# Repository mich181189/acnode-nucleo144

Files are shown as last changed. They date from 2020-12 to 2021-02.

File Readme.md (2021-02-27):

ACNode Nucleo-144 Overlay
=========

# What Is This?
This is an **unfinished** design for an addon board to fit a Nucleo-144, turning it into an ACNode.

# Why?
The current ACNode hardware and software (https://github.com/londonhackspace/acnode-cl) is based around a TI Connected Launchpad. These no doubt looked cool when they were new, but there haven't been any new revisions for some time. On top of this, the current code is based around Energia, an Arduino port for TI Connected Launchpads.

Nowadays, there are other inexpensive development boards available with Ethernet. ST make a large range of Nucleo-144 boards for various microcontrollers. They're more capable, and seem to have better software support.

The software could really do with a rewrite anyway, so there isn't much lost there. It should be possible to make software that builds for both TI Connected Launchpads and ST Nucleo boards (Early-ish work based on FreeRTOS here: https://github.com/mich181189/acnode-cl)

# Features
* Connects to a Nucleo-144 board
* Provides connections to both existing 8P8C readers and the new (still in development, though coming along nicely) RS-422 connected serial readers
* 7-12V input with reverse polarity protection
* SPI Flash for configuration and card caching
* On-board LED mirroring reader LED
* Isolated Tool On input (should accept 3.3-12V)
* Relay for turning on tools, opening doors e.t.c

# Changes from Existing ACNode Boards

* SPI Flash instead of SDCard
I don't think we've ever actually fitted the SD Card. The STM32 MCUs don't have built-in EEPROMs, and we need somewhere to store configuration. Putting these two observations together, it makes sense to fit some SPI storage (EEPROM or Flash) for storage. EEPROMs are easier to write small amounts to, but are smaller. Flash has a lower write cycle count, however tend to be larger, and with a wear levelling filesystem, should be fine.

* On-board LED
When an ACNode is mounted to the other side of a door to its reader, it can be difficult to see the state of the reader since the LED is on the other side of a door. The obvious solution to this is to also put an LED on the ACNode.

* On-board Button
Similar to the on-board LED, this mirrors the functionality of the button on the reader, for easier maintainence

* Isolated tool on pin
Tools can be noisy. By isolating the tool on signal using an optoisolator, we can reduce coupling between the tool and the ACNode.

* Provides RS-422 reader connection
Since we want to be able to use the new reader boards, we need a way to conect them.

* 7-12V input with reverse polarity protection
Not exactly a new requirement, but the Nucleo-144 boards have regulators built in with 7-12V input range, so we may as well add this as an option. Reverse polarity protection because it makes sense to have! A previous board does have a reverse-biased diode for polarity "protection" but it's probably more of a smoke signal.

# Nucleo-144 Boards
Nucleo-144 boards do vary a bit. This board is intended to work with the following boards (which have basically the same pin usage), however will probably work with many other Nucleo-144 boards:

| Board | Features | Example Price | Example Source |
| ----- | --- | --- | --- |
| NUCLEO-H743ZI2 | Arm Cortex M7 with 2MB Flash, 1MB RAM, L1 Cache, running at up to 480MHz | £26.21 | [https://uk.rs-online.com/web/p/microcontroller-development-tools/1939787/](RS 193-9787) |
| NUCLEO-F767ZI | Arm Cortex M7 with 2MB Flash, 512KB RAM, L1 Cache, running at up to 216MHz | £22.38 | [https://uk.rs-online.com/web/p/microcontroller-development-tools/1231052/](RS 123-1052) |
| NUCLEO-F756ZG | Arm Cortex M7 with 1MB Flash, 320KB RAM, L1 Cache, HW Crypto, running at up to 216MHz | £22.31 | [https://uk.rs-online.com/web/p/microcontroller-development-tools/1750680/](RS 175-0680) |

# TODO
* Exit Button Support
* A jumper on the ISL3176 ~RE line would allow a single	board to support 5V and 12V readers
* Footprints for 3.81mm	connectors are too tight - holes too small

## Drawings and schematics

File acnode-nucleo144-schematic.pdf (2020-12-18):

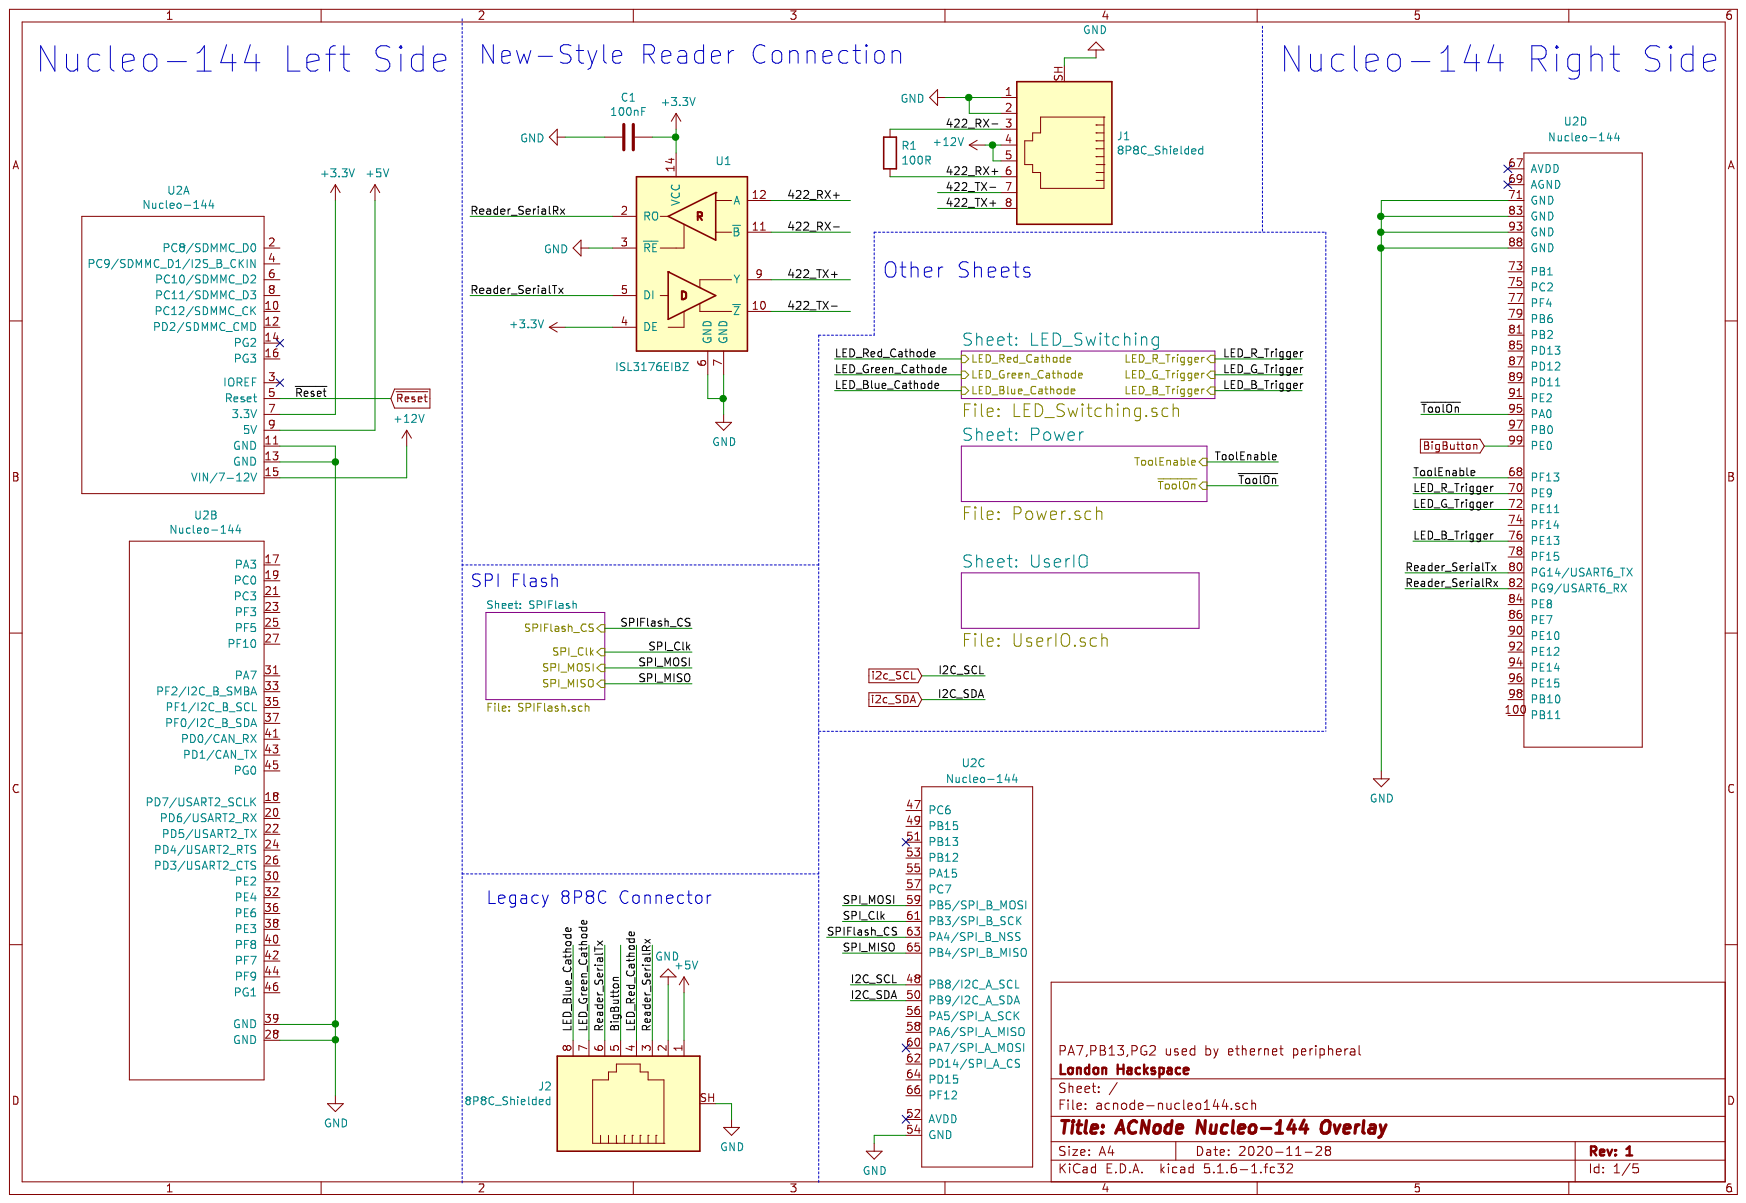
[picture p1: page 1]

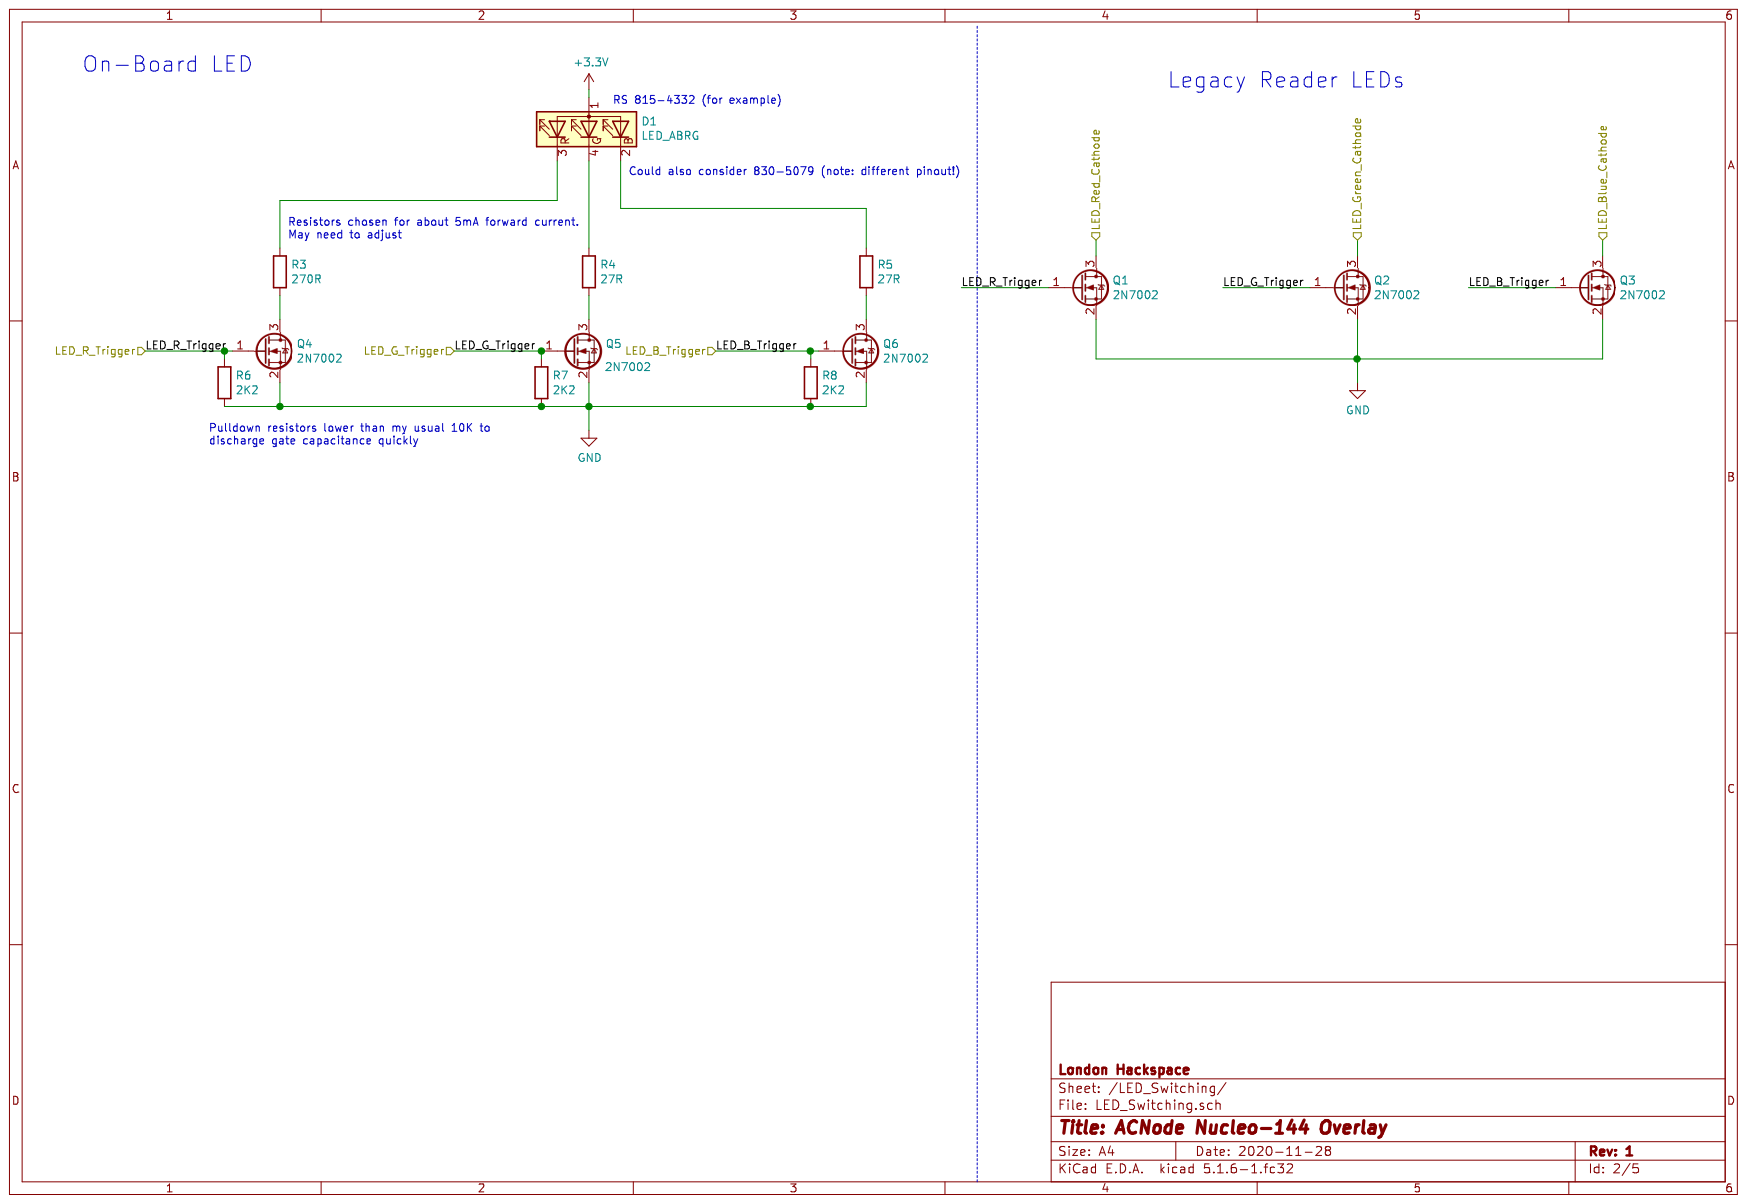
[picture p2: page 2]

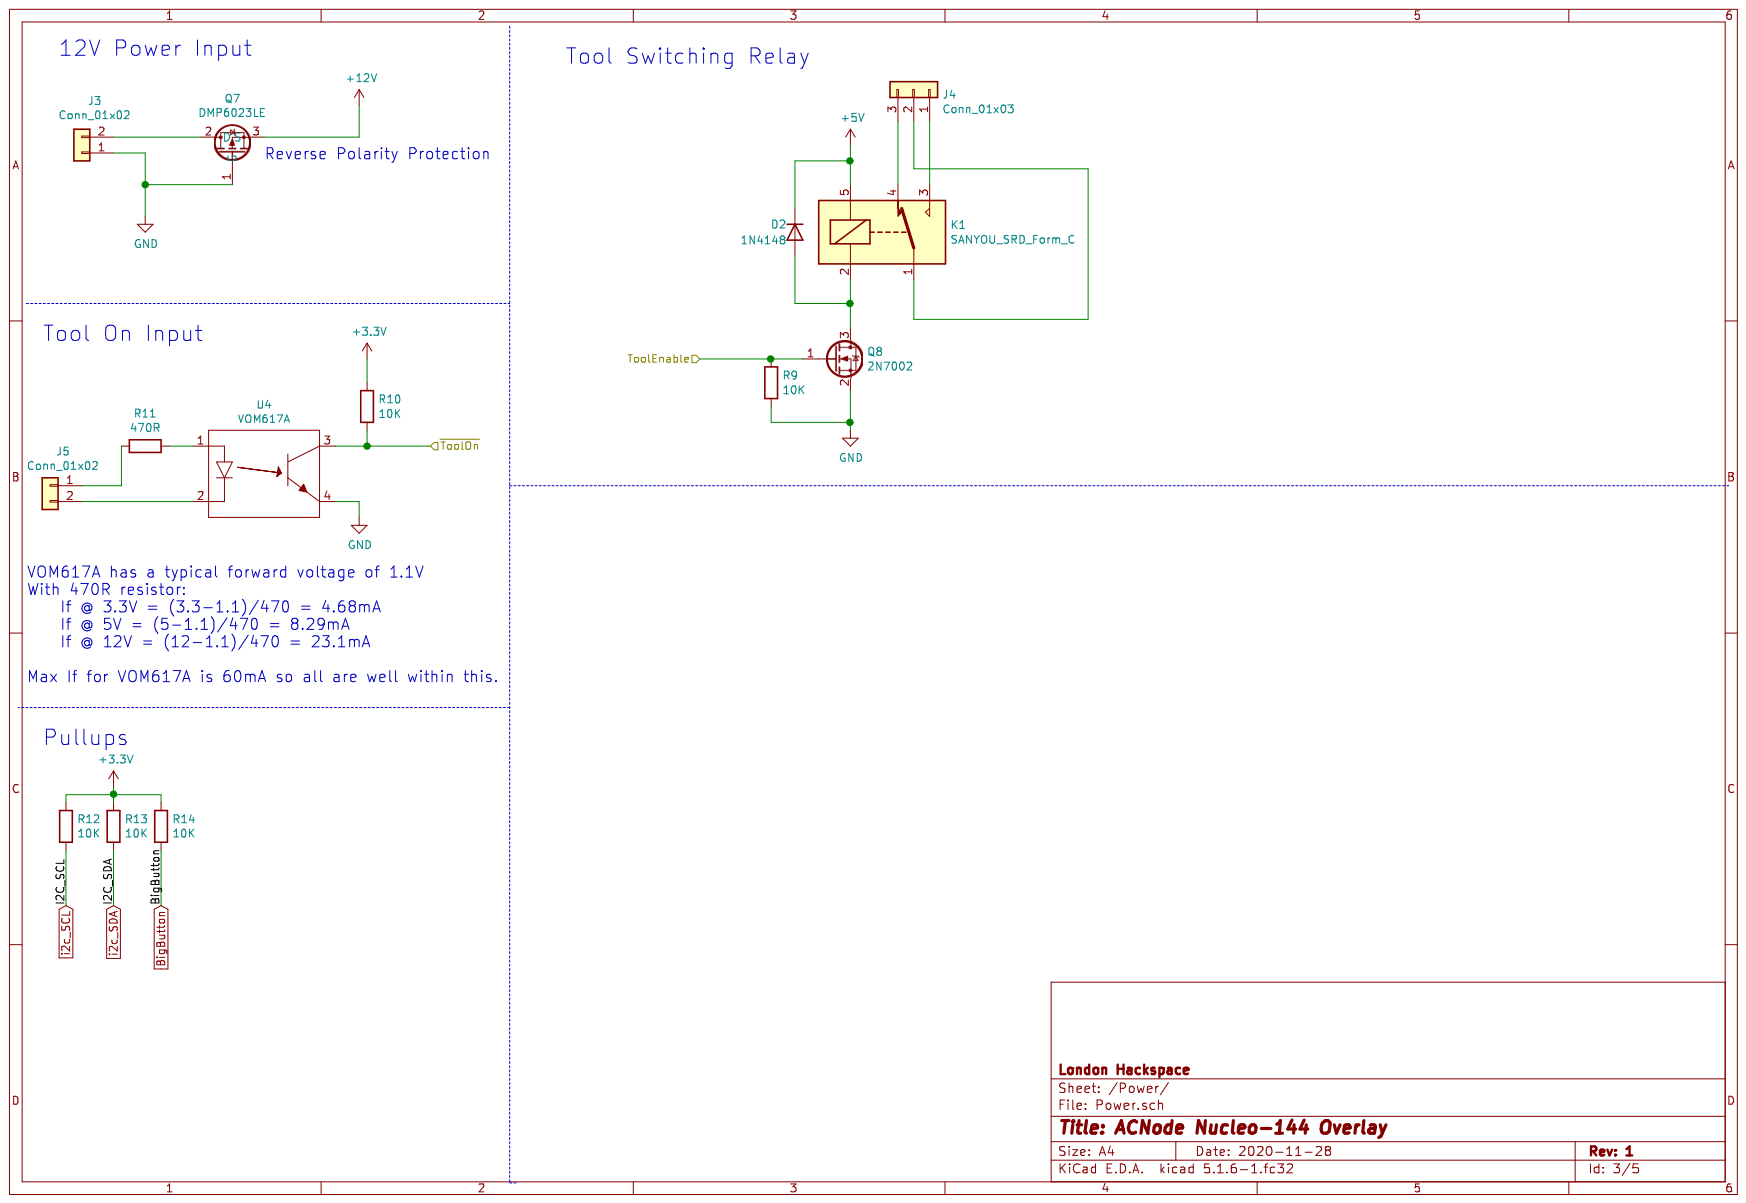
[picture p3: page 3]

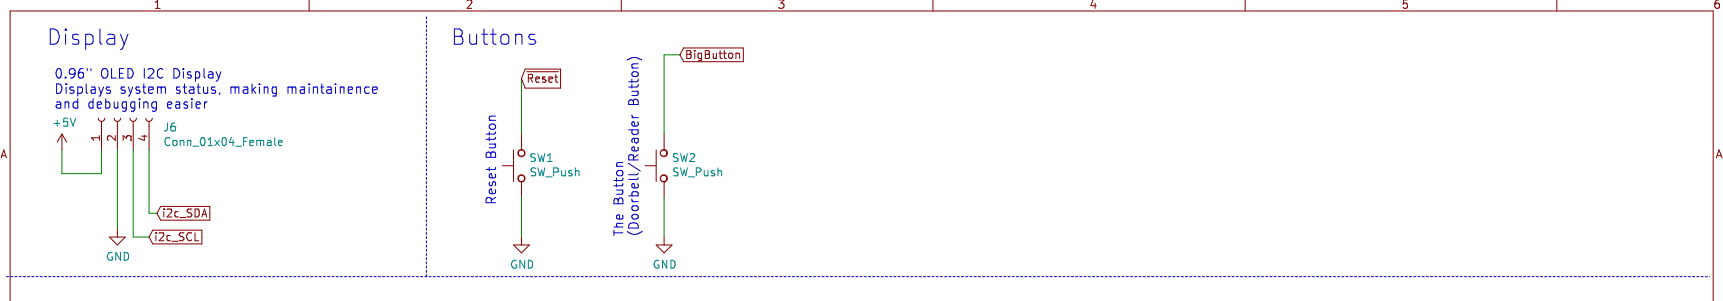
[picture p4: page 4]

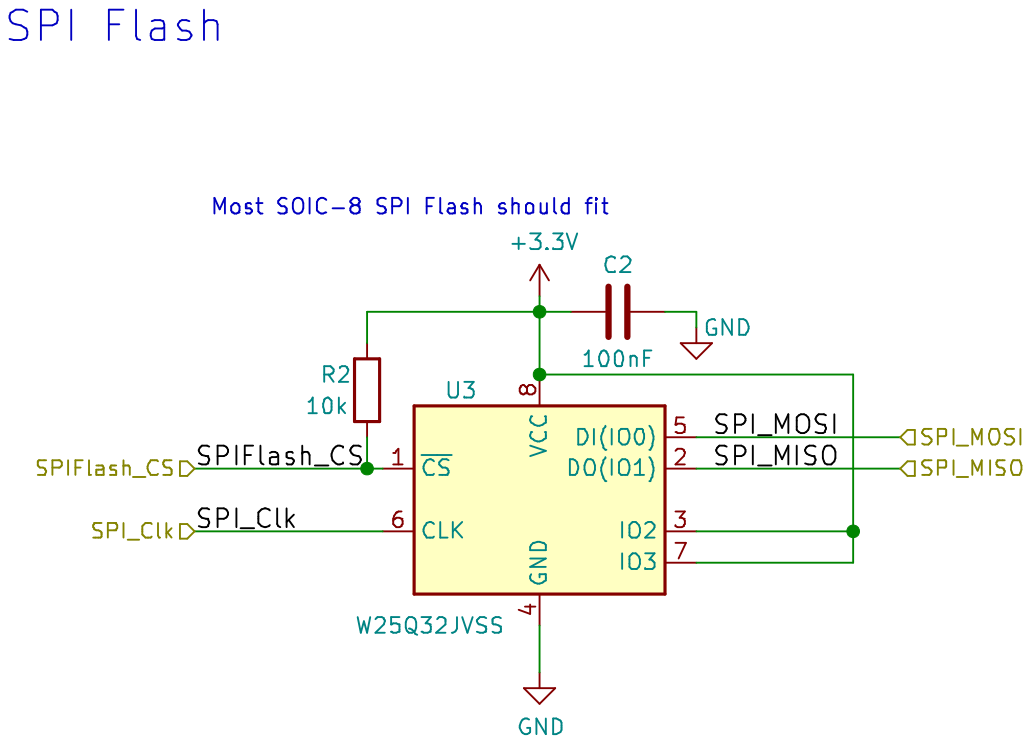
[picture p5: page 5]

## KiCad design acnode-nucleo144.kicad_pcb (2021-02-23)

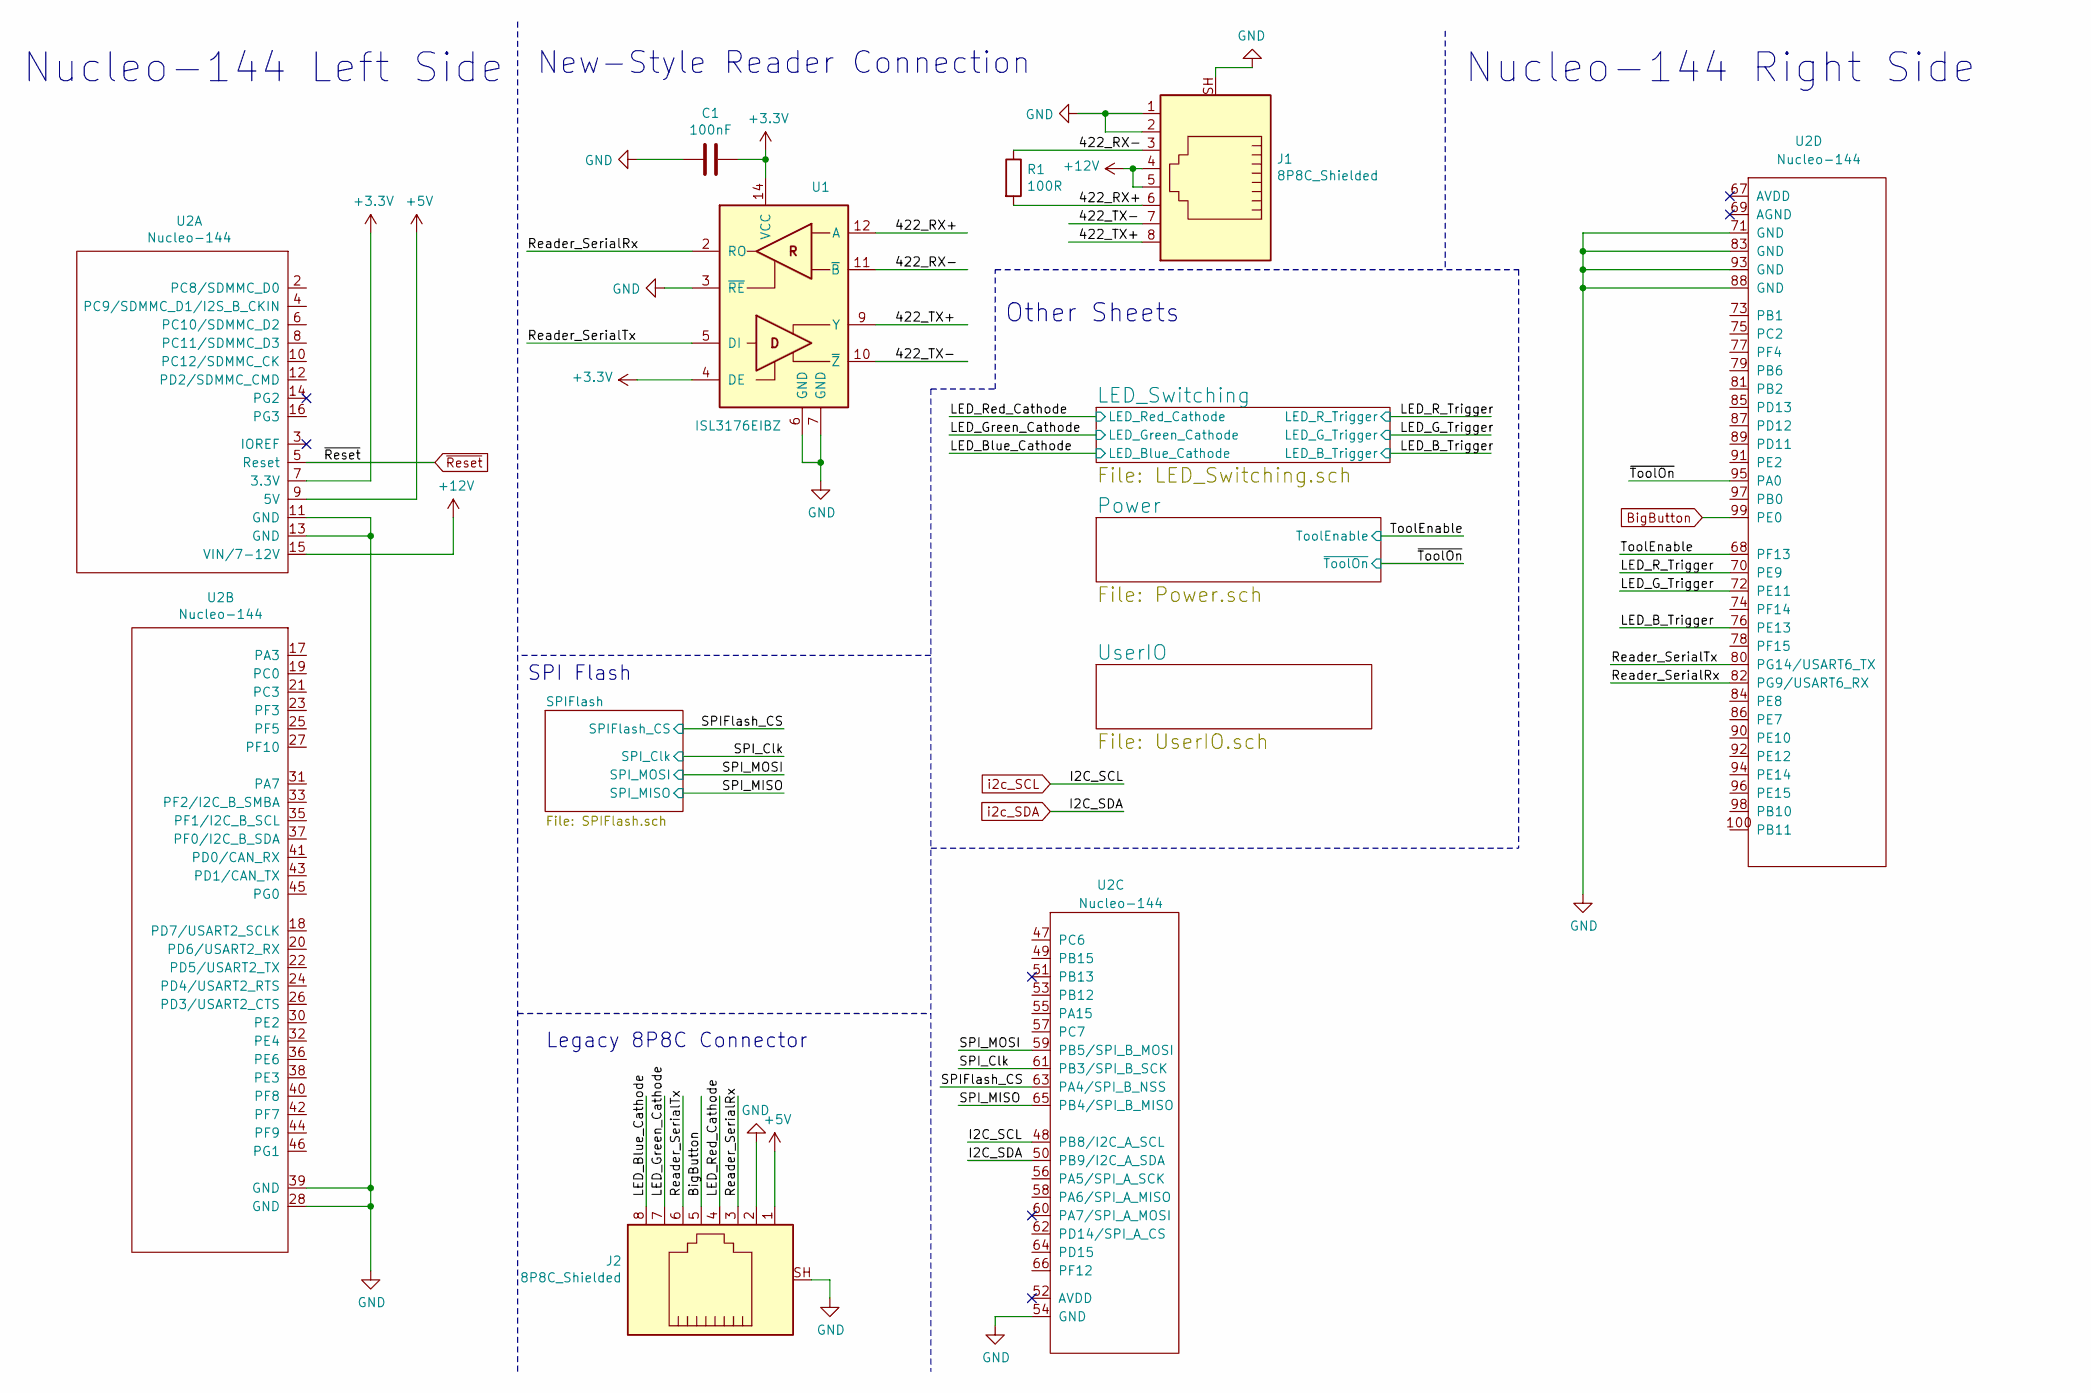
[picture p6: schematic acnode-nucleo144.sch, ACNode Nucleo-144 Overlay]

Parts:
C1: 100nF; C_0603_1608Metric
J1, J2: 8P8C_Shielded; RJ45_Ninigi_GE
R1: 100R; R_0603_1608Metric
U1: ISL3176EIBZ; SOIC-14_3.9x8.7mm_P1.27mm
U2: Nucleo-144

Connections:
+3V3: C1.1, U1.4 (DE), U1.14 (VCC), U2.7 (3.3V); also elsewhere on the board
+5V: J2.1, U2.9 (5V); also elsewhere on the board
+12V: J1.4, J1.5, U2.15 (VIN/7-12V); also elsewhere on the board
/422_RX+: J1.6, R1.2, U1.12 (A)
/422_RX-: J1.3, R1.1, U1.11 (~B)
/422_TX+: J1.8, U1.9 (Y)
/422_TX-: J1.7, U1.10 (~Z~)
/LED_B_Trigger: U2.76 (PE13); also elsewhere on the board
/LED_Blue_Cathode: J2.8; also elsewhere on the board
/LED_G_Trigger: U2.72 (PE11); also elsewhere on the board
/LED_Green_Cathode: J2.7; also elsewhere on the board
/LED_R_Trigger: U2.70 (PE9); also elsewhere on the board
/LED_Red_Cathode: J2.4; also elsewhere on the board
/Reader_SerialRx: J2.3, U1.2 (RO), U2.82 (PG9/USART6_RX)
/Reader_SerialTx: J2.6, U1.5 (DI), U2.80 (PG14/USART6_TX)
/SPIFlash_CS: U2.63 (PA4/SPI_B_NSS); also elsewhere on the board
/SPI_Clk: U2.61 (PB3/SPI_B_SCK); also elsewhere on the board
/SPI_MISO: U2.65 (PB4/SPI_B_MISO); also elsewhere on the board
/SPI_MOSI: U2.59 (PB5/SPI_B_MOSI); also elsewhere on the board
/ToolEnable: U2.68 (PF13); also elsewhere on the board
/~ToolOn: U2.95 (PA0); also elsewhere on the board
BigButton: J2.5, U2.99 (PE0); also elsewhere on the board
GND: C1.2, J1.1, J1.2, J1.SH, J2.2, J2.SH, U1.3 (~RE), U1.6 (GND), U1.7 (GND), U2.11 (GND), U2.13 (GND), U2.28 (GND), U2.39 (GND), U2.54 (GND), U2.71 (GND), U2.83 (GND), U2.88 (GND), U2.93 (GND); also elsewhere on the board
i2c_SCL: U2.48 (PB8/I2C_A_SCL); also elsewhere on the board
i2c_SDA: U2.50 (PB9/I2C_A_SDA); also elsewhere on the board
~Reset: U2.5 (Reset); also elsewhere on the board

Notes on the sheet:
Nucleo-144 Left Side
Nucleo-144 Right Side
Legacy 8P8C Connector
SPI Flash
New-Style Reader Connection
Other Sheets

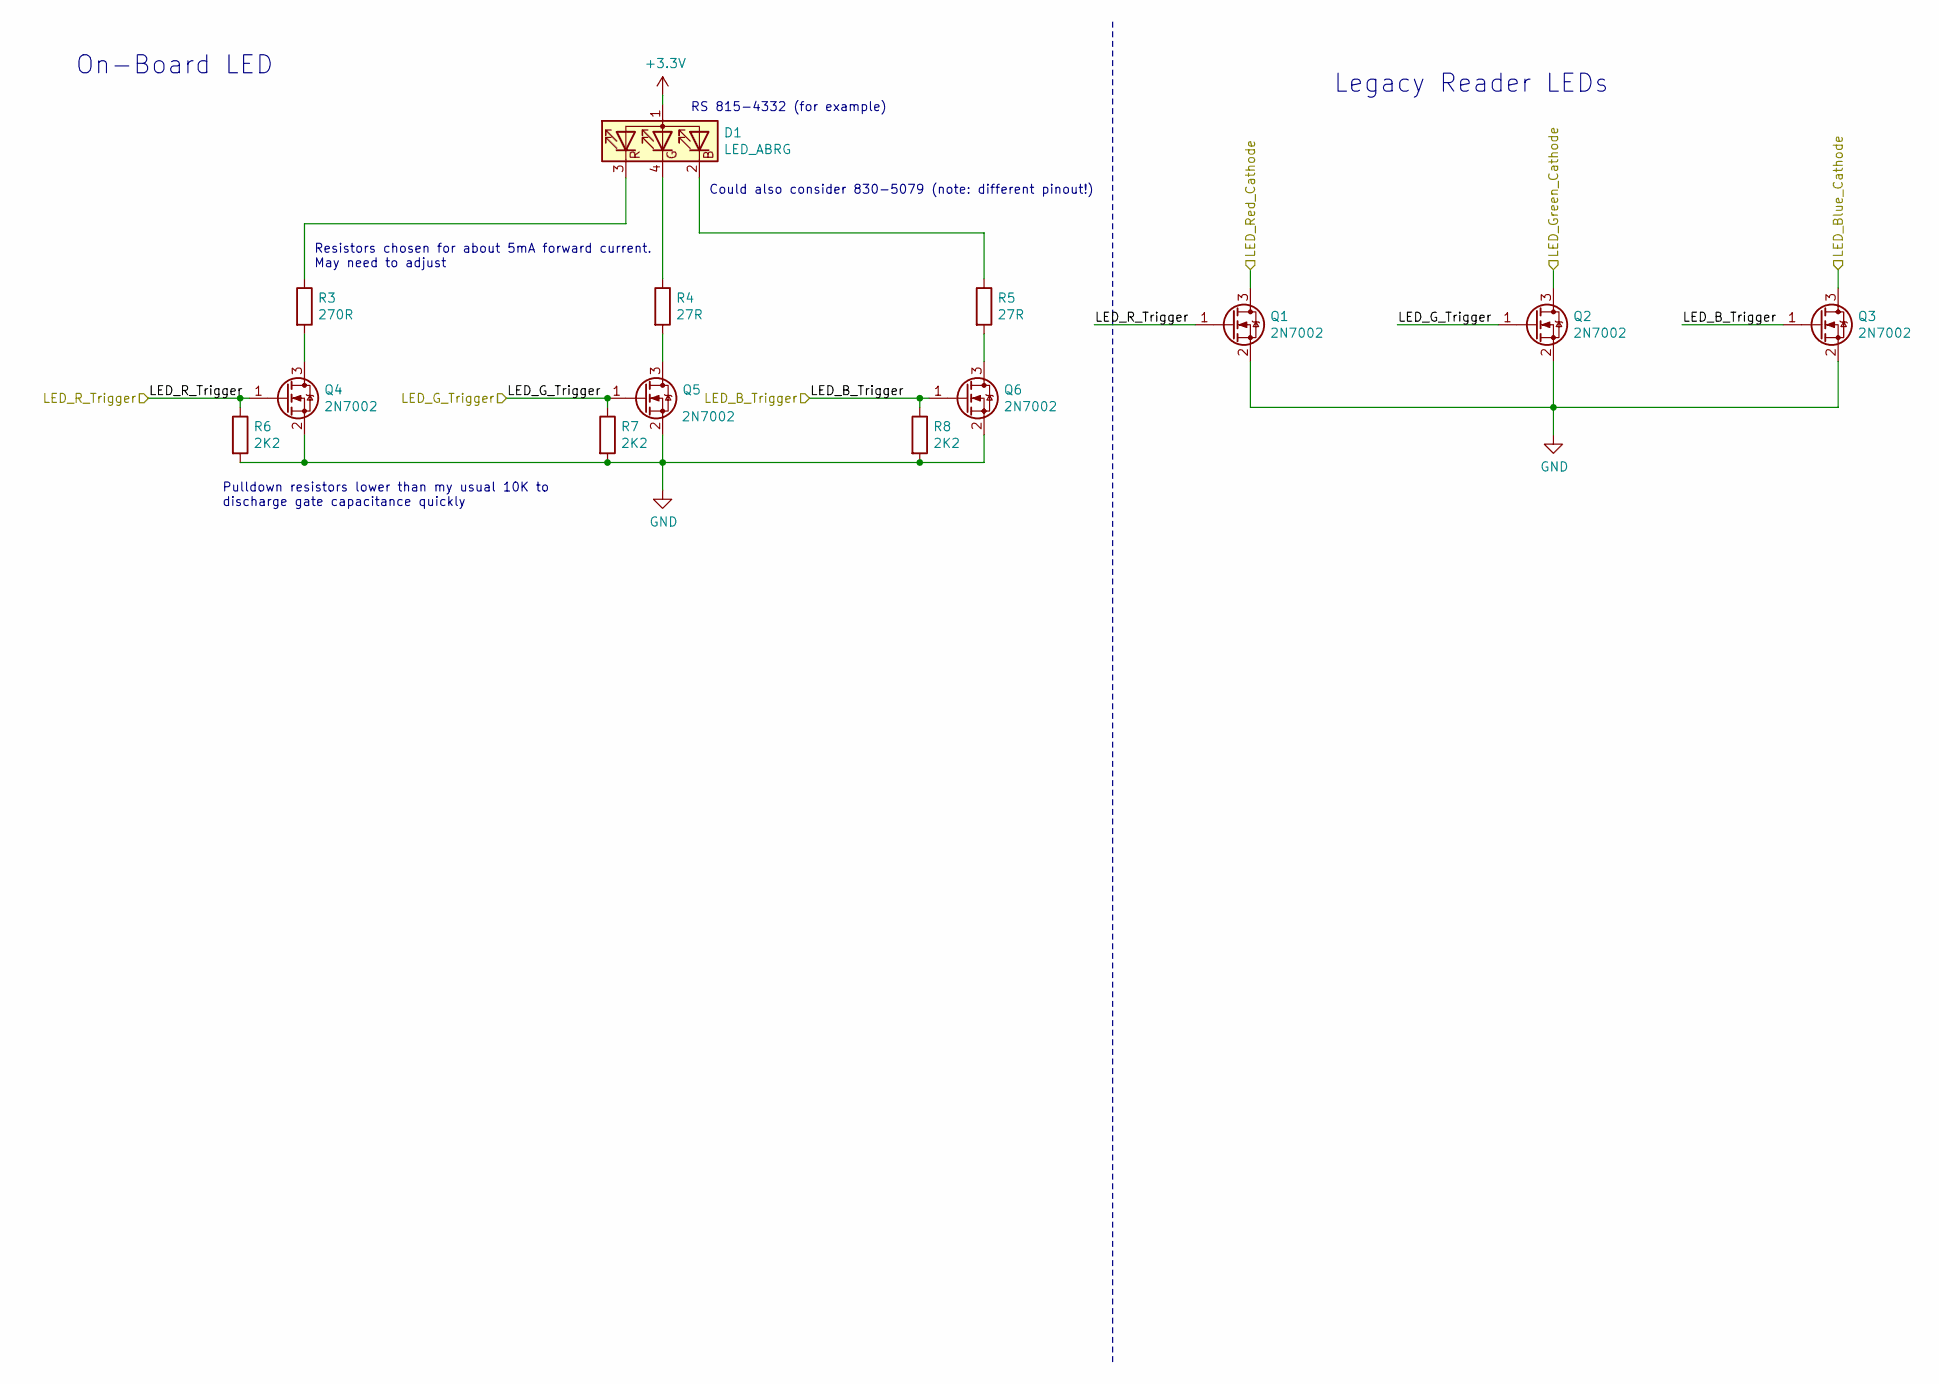
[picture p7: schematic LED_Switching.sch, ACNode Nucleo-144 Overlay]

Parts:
D1: LED_ABRG; Wurth_3528_LED
Q1, Q2, Q3, Q4, Q5, Q6: 2N7002; SOT-23
R3: 270R; R_0603_1608Metric
R4, R5: 27R; R_0603_1608Metric
R6, R7, R8: 2K2; R_0603_1608Metric

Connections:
+3V3: D1.1 (A); also elsewhere on the board
/LED_B_Trigger: Q3.1 (G), Q6.1 (G), R8.1; also elsewhere on the board
/LED_Blue_Cathode: Q3.3 (D); also elsewhere on the board
/LED_G_Trigger: Q2.1 (G), Q5.1 (G), R7.1; also elsewhere on the board
/LED_Green_Cathode: Q2.3 (D); also elsewhere on the board
/LED_R_Trigger: Q1.1 (G), Q4.1 (G), R6.1; also elsewhere on the board
/LED_Red_Cathode: Q1.3 (D); also elsewhere on the board
GND: Q1.2 (S), Q2.2 (S), Q3.2 (S), Q4.2 (S), Q5.2 (S), Q6.2 (S), R6.2, R7.2, R8.2; also elsewhere on the board
unnamed: D1.2 (BK), R5.1
unnamed: D1.3 (RK), R3.1
unnamed: D1.4 (GK), R4.1
unnamed: Q4.3 (D), R3.2
unnamed: Q5.3 (D), R4.2
unnamed: Q6.3 (D), R5.2

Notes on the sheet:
RS 815-4332 (for example)
On-Board LED
Legacy Reader LEDs
Pulldown resistors lower than my usual 10K to discharge gate capacitance quickly
Could also consider 830-5079 (note: different pinout!)
Resistors chosen for about 5mA forward current. May need to adjust

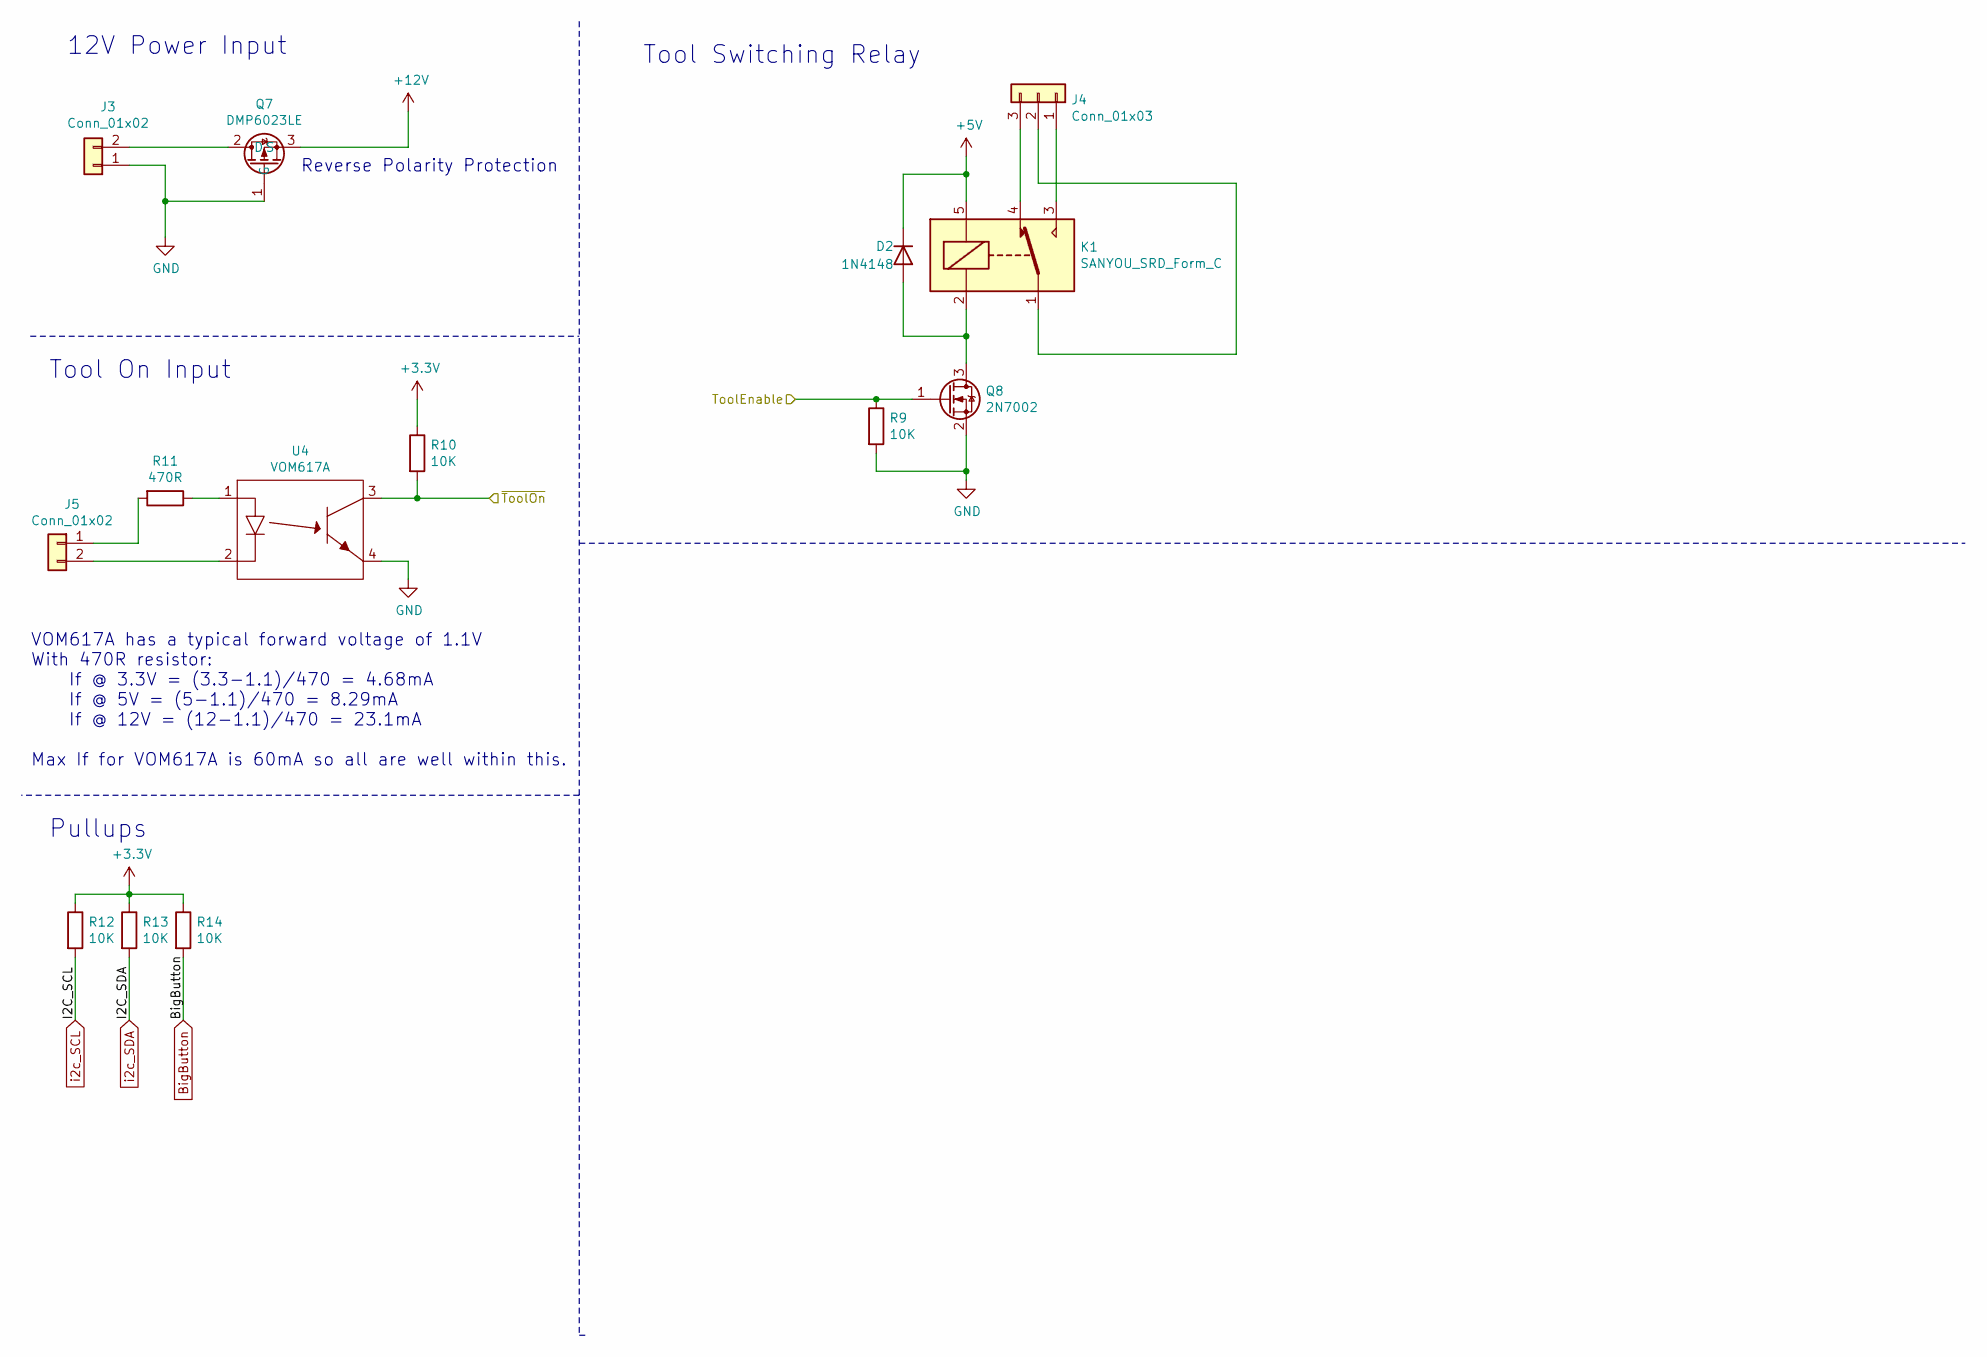
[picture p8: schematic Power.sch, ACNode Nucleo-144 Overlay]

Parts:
D2: 1N4148; D_DO-35_SOD27_P7.62mm_Horizontal
J3: Conn_01x02; Connector-5.08mm
J4: Conn_01x03; Connector-3.81mm-3pin
J5: Conn_01x02; Connector-3.81mm-2pin
K1: SANYOU_SRD_Form_C; Relay_SPDT_SANYOU_SRD_Series_Form_C
Q7: DMP6023LE; SOT-223
Q8: 2N7002; SOT-23
R9, R10, R12, R13, R14: 10K; R_0603_1608Metric
R11: 470R; R_0603_1608Metric
U4: VOM617A; VOM617A-4SOP

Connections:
+3V3: R10.1, R12.1, R13.1, R14.1; also elsewhere on the board
+5V: D2.1 (K), K1.5; also elsewhere on the board
+12V: Q7.3 (S); also elsewhere on the board
/ToolEnable: Q8.1 (G), R9.1; also elsewhere on the board
/~ToolOn: R10.2, U4.3; also elsewhere on the board
BigButton: R14.2; also elsewhere on the board
GND: J3.1, Q7.1 (G), Q8.2 (S), R9.2, U4.4; also elsewhere on the board
unnamed: D2.2 (A), K1.2, Q8.3 (D)
unnamed: J3.2, Q7.2 (D), Q7.4 (Tab)
unnamed: J4.1, K1.3
unnamed: J4.2, K1.1
unnamed: J4.3, K1.4
unnamed: J5.1, R11.2
unnamed: J5.2, U4.2
unnamed: R11.1, U4.1
i2c_SCL: R12.2; also elsewhere on the board
i2c_SDA: R13.2; also elsewhere on the board

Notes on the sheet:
Reverse Polarity Protection
12V Power Input
Tool Switching Relay
Tool On Input
VOM617A has a typical forward voltage of 1.1V With 470R resistor: If @ 3.3V = (3.3-1.1)/470 = 4.68mA If @ 5V = (5-1.1)/470 = 8.29mA If @ 12V = (12-1.1)/470 = 23.1mA Max If for VOM617A is 60mA so all are well within this.
Pullups

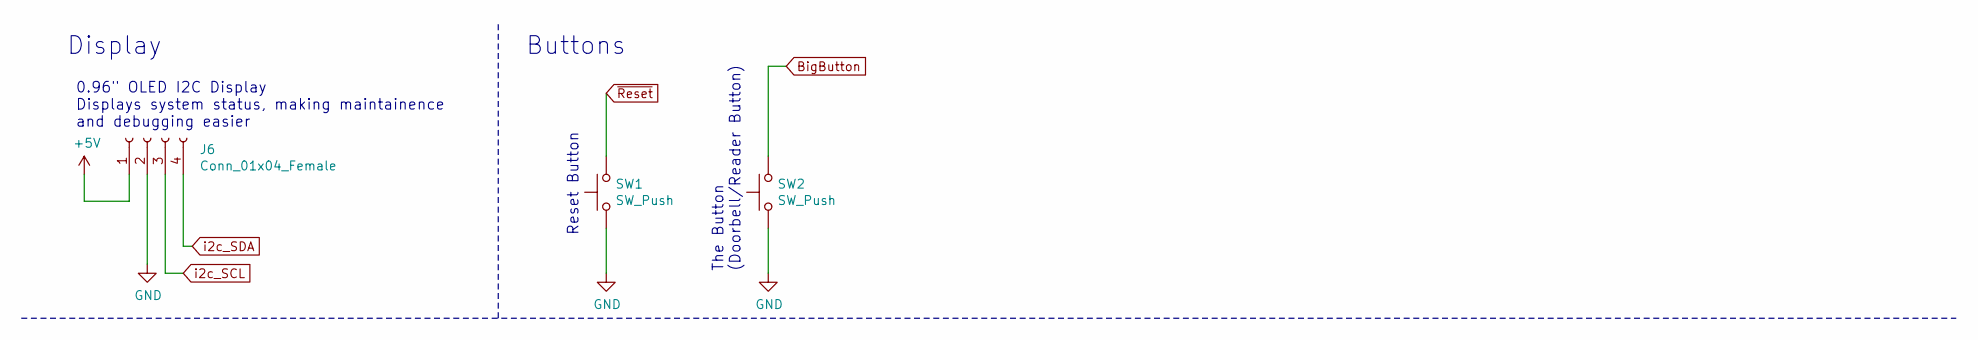
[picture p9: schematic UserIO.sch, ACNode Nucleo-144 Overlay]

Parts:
J6: Conn_01x04_Female; PinHeader_1x04_P2.54mm_Vertical
SW1, SW2: SW_Push; SW_PUSH_6mm

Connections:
+5V: J6.1; also elsewhere on the board
BigButton: SW2.2; also elsewhere on the board
GND: J6.2, SW1.1, SW2.1; also elsewhere on the board
i2c_SCL: J6.3; also elsewhere on the board
i2c_SDA: J6.4; also elsewhere on the board
~Reset: SW1.2; also elsewhere on the board

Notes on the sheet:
Display
0.96" OLED I2C Display Displays system status, making maintainence and debugging easier
Buttons
Reset Button
The Button (Doorbell/Reader Button)

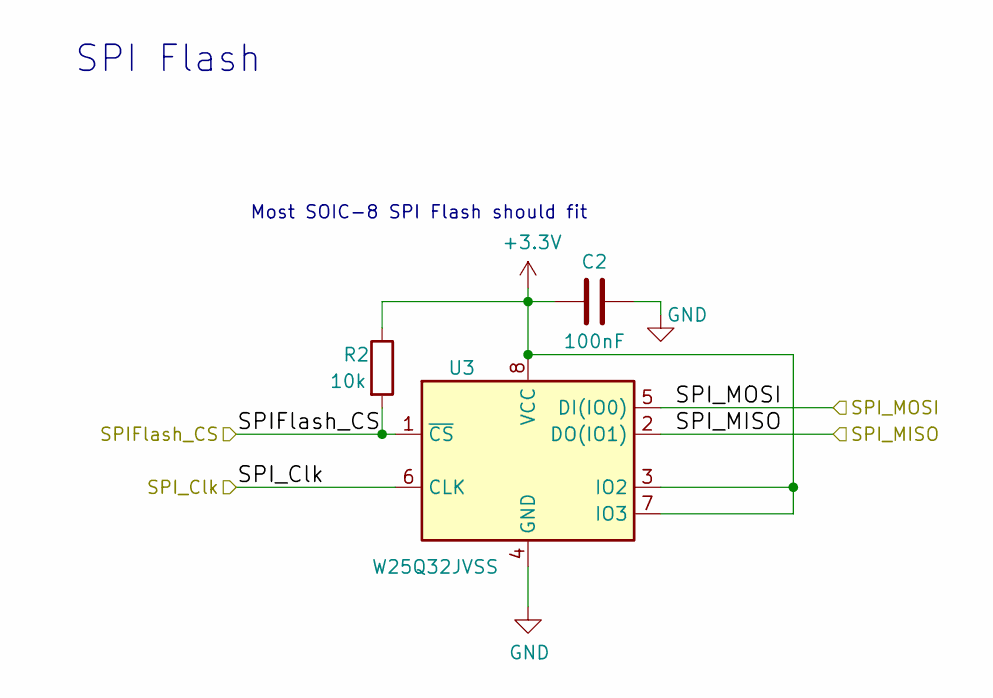
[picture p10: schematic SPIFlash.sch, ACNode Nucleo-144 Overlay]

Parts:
C2: 100nF; C_0603_1608Metric
R2: 10k; R_0603_1608Metric
U3: W25Q32JVSS; SOIC-8_5.23x5.23mm_P1.27mm

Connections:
+3V3: C2.2, R2.1, U3.3 (IO2), U3.7 (IO3), U3.8 (VCC); also elsewhere on the board
/SPIFlash_CS: R2.2, U3.1 (~CS); also elsewhere on the board
/SPI_Clk: U3.6 (CLK); also elsewhere on the board
/SPI_MISO: U3.2 (DO(IO1)); also elsewhere on the board
/SPI_MOSI: U3.5 (DI(IO0)); also elsewhere on the board
GND: C2.1, U3.4 (GND); also elsewhere on the board

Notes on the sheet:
Most SOIC-8 SPI Flash should fit
SPI Flash

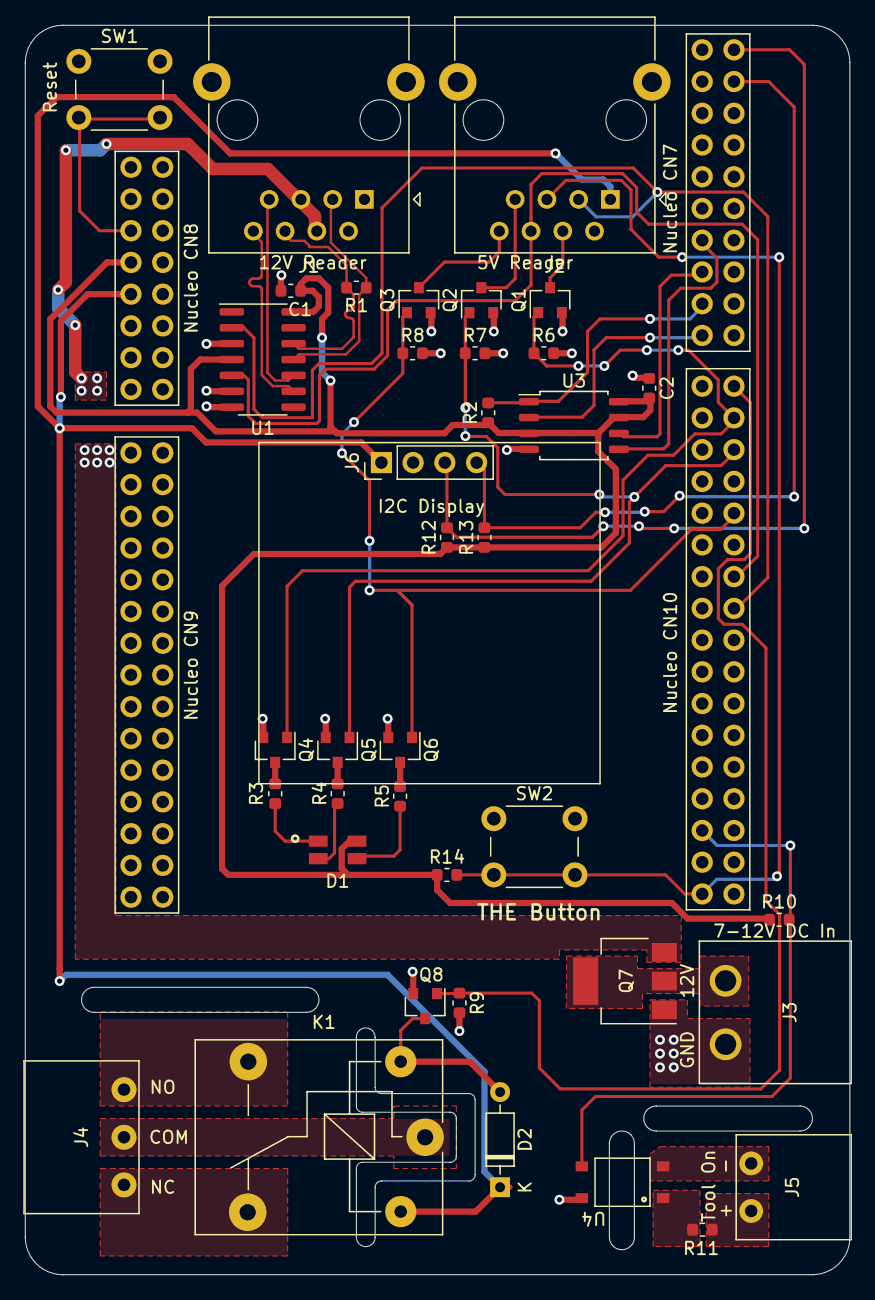
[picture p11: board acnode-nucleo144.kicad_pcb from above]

Board: 2 copper layers, 66.0 x 100.0 mm, 39 parts (0 on the bottom side), 40 nets.

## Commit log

2020-11-28 Initial commit of draft
    [LED_Switching.sch, Power.sch, UserIO.sch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]
2020-11-28 Annotated some symbols and linked nets properly between sheets
    [LED_Switching.sch, Power.sch, UserIO.sch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]
2020-11-28 Updated PDF and a few schematic tweaks
    [acnode-nucleo144.sch]
2020-11-29 First pass at routing board fully
    Also fixed a stupid error on the Nucleo-144 footprint
    [LED_Switching.sch, Power.sch, acnode-nucleo144.kicad_pcb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]
2020-11-29 Switched to shielded 8P8C jack
    [acnode-nucleo144.kicad_pcb, acnode-nucleo144.sch]
2020-12-18 Some changes I found on my computer
    [LED_Switching.sch, Power.sch, SPIFlash.sch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]
2021-02-23 I built one. Still obviously needs proper software support to fully test, but it doesn't look bad
    [acnode-nucleo144-B_Cu.gbr, acnode-nucleo144-B_Mask.gbr, acnode-nucleo144-B_Paste.gbr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]
2021-02-27 Added a couple of assembly notes
